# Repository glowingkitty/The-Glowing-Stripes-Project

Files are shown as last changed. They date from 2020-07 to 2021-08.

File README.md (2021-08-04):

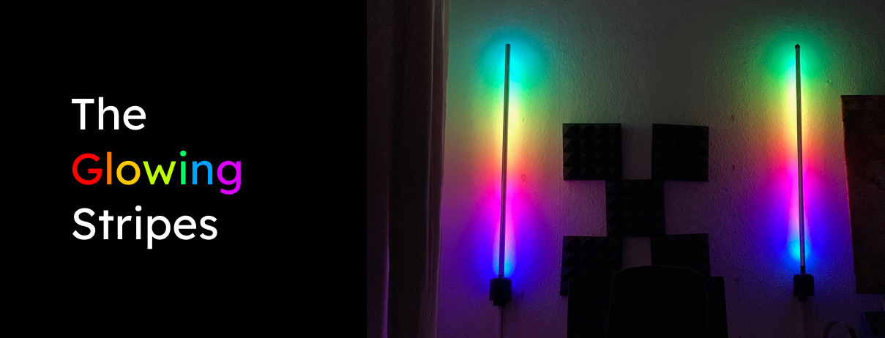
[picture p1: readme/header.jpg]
The Glowing Stripes


## What is this project?

An LED strip system which can be used to light up your home, a house party or even an outdoor party - with it's integrated battery. Every Glowing Stripes unit can glow for many hours in battery mode - or non stop if connected to a power source at home. And with the integrated microphone it's awesome for setting the mood at your home- or openair-party!

How does one control the LED animations, you ask? By accessing the "Glowing Core" interface via your web browser or WLED app for iOS and Android. "The Glowing Core" is a tiny hardware package to control LED strips by the way - and used inside "The Glowing Stripes". [Check out the readme](https://github.com/glowingkitty/TheGlowingCore) to learn more about that project.

## Known issues

Adding a single 1 meter long LED strip (or shorter) to one base unit works perfectly fine. However, when adding multiple LED strips on top of each other, you might notice the LED strips are bending - depending on what kind of material you use for 3D printing the parts. If you 3D print the connecting people out of metal, you shouldn't have to worry. Otherwise it's wise to limit the length to 1 meter per base unit.

## How to build the Glowing Stripes

### **Step 1:** Build the Glowing Core

Check out [the detailed description here](https://github.com/glowingkitty/TheGlowingCore#how-to-build-the-glowing-core) to learn how to build it.

### **Step 2:** 3D print all needed parts

The design was made for printing on an SLA printer (resin 3D printer). But it should also work perfectly fine with an FDM (molten plastic) 3D printer.

Download and print those STL files:

- 1x [main case](https://github.com/glowingkitty/The-Glowing-Stripes-Project/blob/master/3d%20printed%20parts/main_case/main_case.stl)
- 1x [outer case](https://github.com/glowingkitty/The-Glowing-Stripes-Project/blob/master/3d%20printed%20parts/main_case/outer_case.stl)
- 1x [female a connector](https://github.com/glowingkitty/The-Glowing-Stripes-Project/blob/master/3d%20printed%20parts/connector/female_a.stl)
- 1x [female b connector](https://github.com/glowingkitty/The-Glowing-Stripes-Project/blob/master/3d%20printed%20parts/connector/female_b.stl)
- 1x [male a connector](https://github.com/glowingkitty/The-Glowing-Stripes-Project/blob/master/3d%20printed%20parts/connector/male_a.stl) (make sure to use a very strong filament, resin or best: 3d print it with metal)
- 1x [male b connector](https://github.com/glowingkitty/The-Glowing-Stripes-Project/blob/master/3d%20printed%20parts/connector/male_b.stl)

And depending on how you want to position "The Glowing Stripes"...

Stand on furniture or the ground, indoor:

- 1x [mini stand](https://github.com/glowingkitty/The-Glowing-Stripes-Project/blob/master/3d%20printed%20parts/stand/mini_stand.stl)

Hang on the wall:

- 1x [wall stand](https://github.com/glowingkitty/The-Glowing-Stripes-Project/blob/master/3d%20printed%20parts/stand/wall_stand.stl)

Stand outdoor:

- 3x [stand](https://github.com/glowingkitty/The-Glowing-Stripes-Project/blob/master/3d%20printed%20parts/stand/stand.stl)

### **Step 3:** Get all the other parts you need

Here is what you need:

- 1x [22AWG JST Connector 3-Pin Male](https://aliexpress.com/item/1005001779302510.html)
- 1x [22AWG JST Connector 3-Pin Female](https://aliexpress.com/item/1005001779302510.html)
- 1x [V shape aluminium profile - 50cm or 1m](https://aliexpress.com/item/1005002834175693.html)
- 1x [WS2812B LED strip, 30 LEDs per meter, white - 50cm or 1m](https://aliexpress.com/item/2036819167.html)
- (optional) 1x [3000mAh lipo battery](https://www.amazon.de/-/en/Seamuing-Protective-Insulation-Connector-Development/dp/B08V11Z88Q)
- 4x M3 14mm screws
- 4x M3 square nuts

### **Step 4:** Connect The Glowing Core to main case

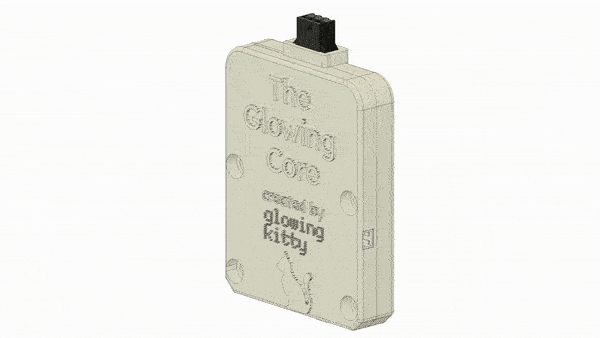
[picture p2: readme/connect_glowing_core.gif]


Add the M3 nuts into the main case, place the Glowing Core in it and screw it together. Optionally: place the 3000mAh lipo inside as well and connect it with The Glowing Core.

### **Step 5:** Finish base unit

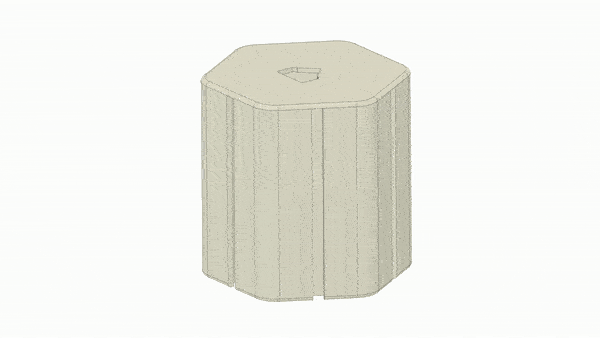
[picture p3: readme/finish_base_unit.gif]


Addd M3 nuts into the outer case, place it on top of the main case and screw it together.

### **Step 6:** Build the connectors

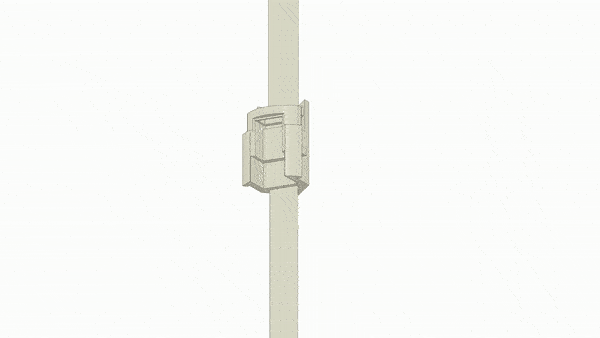
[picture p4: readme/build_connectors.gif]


Place the male 3-pin connector into the male connector a, close it with male connector b and repeat the same for the female connector.

### **Step 7:** Complete the LED strips

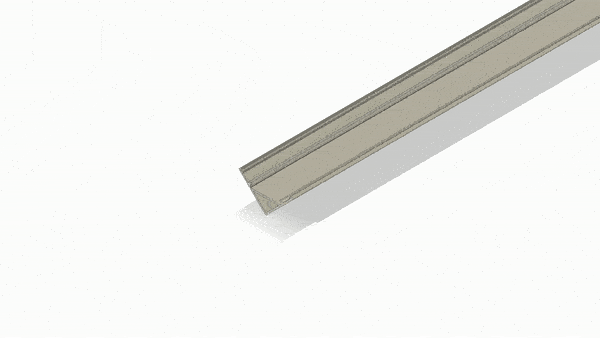
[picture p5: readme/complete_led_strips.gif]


Tape the LED strips on the aluminium profile & remove the foil from the aluminium profile cover, place the connectors on the two ends of the profile and then solder the wires to the LED strips. Make sure the male connector gets soldered to the beginning of the LED strip! Pay attention to the arrow on the WS2812B LED strip (it must point away from the connector). Remove the transparent foil from the aluminium profile diffuser. Then cover the aluminium profile with the diffuser.

### **Step 8:** Complete the Glowing Stripes

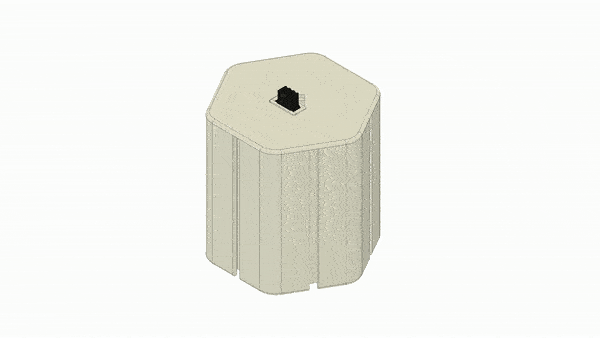
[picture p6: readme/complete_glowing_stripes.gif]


Place the LED strip on the base unit & place the base unit on the stand of your choice.

### **Step 9:** Turn it on and let it glow!

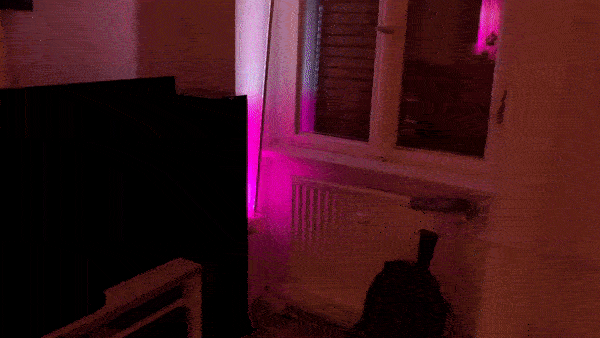
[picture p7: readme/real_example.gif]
Let it glow!


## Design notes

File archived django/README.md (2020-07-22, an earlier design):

# The Glowing Stripes Project

A portable and flexible LED setup. Use it to light up your whole room, or just some area. All stripes are connected via WiFi to the main controller - and can operate for hours without any power plug, thanks to their integrated battery.

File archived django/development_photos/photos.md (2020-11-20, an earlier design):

## The latest development in photos...

The new 3D printed case design (1 of 2 parts - design needs some more smaller fixes):
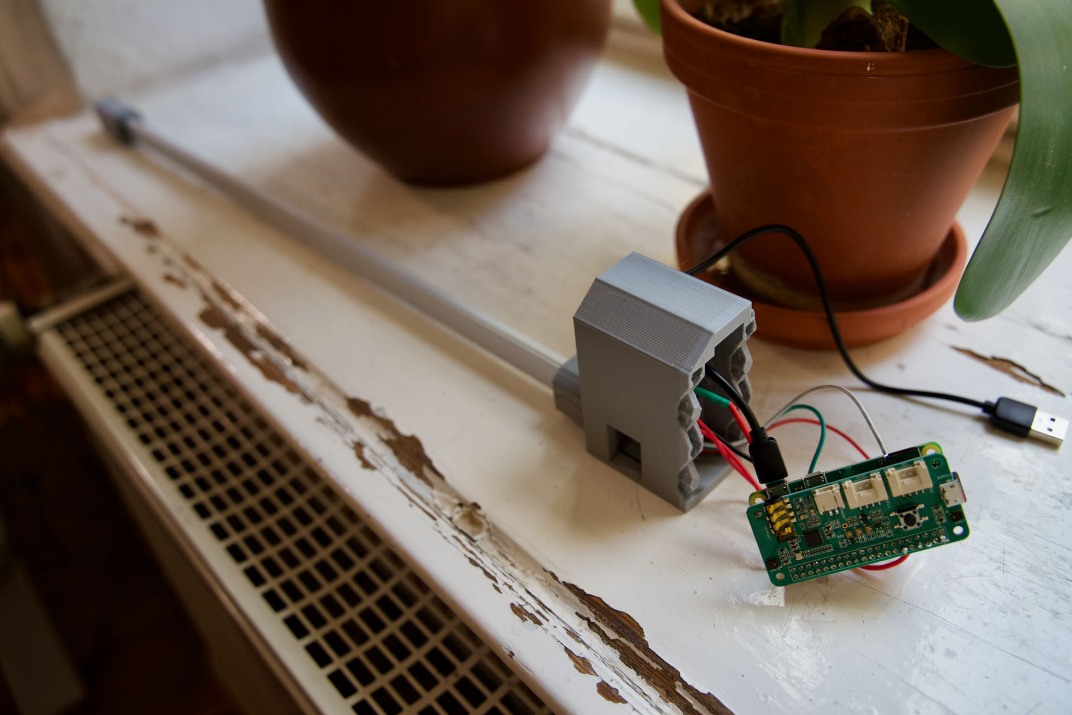
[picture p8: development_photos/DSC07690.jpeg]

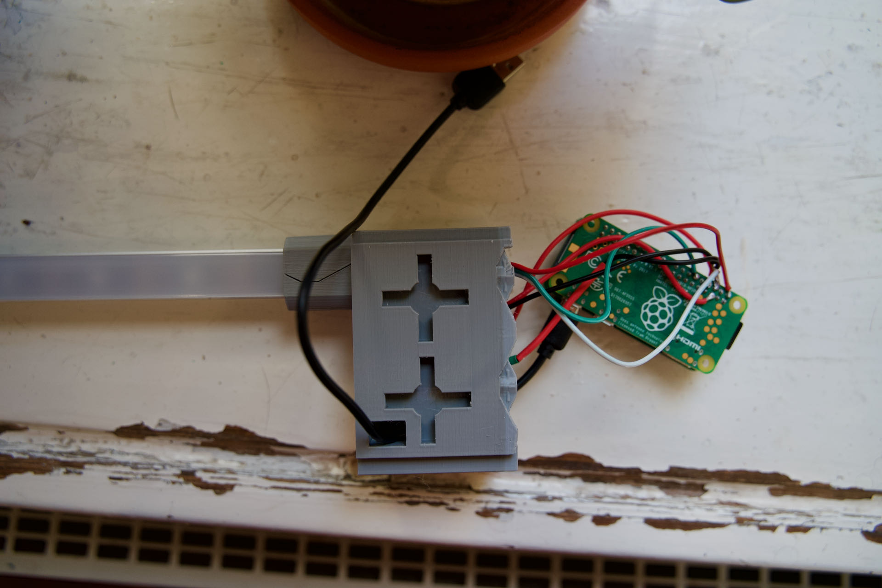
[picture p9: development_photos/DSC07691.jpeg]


Rainbow animation:
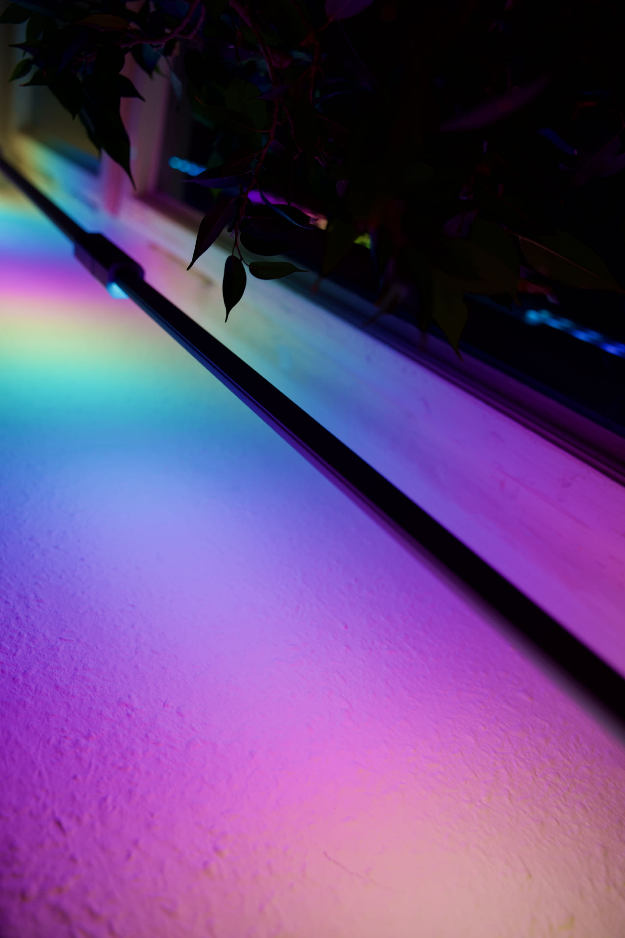
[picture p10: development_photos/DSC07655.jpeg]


The new connector design:
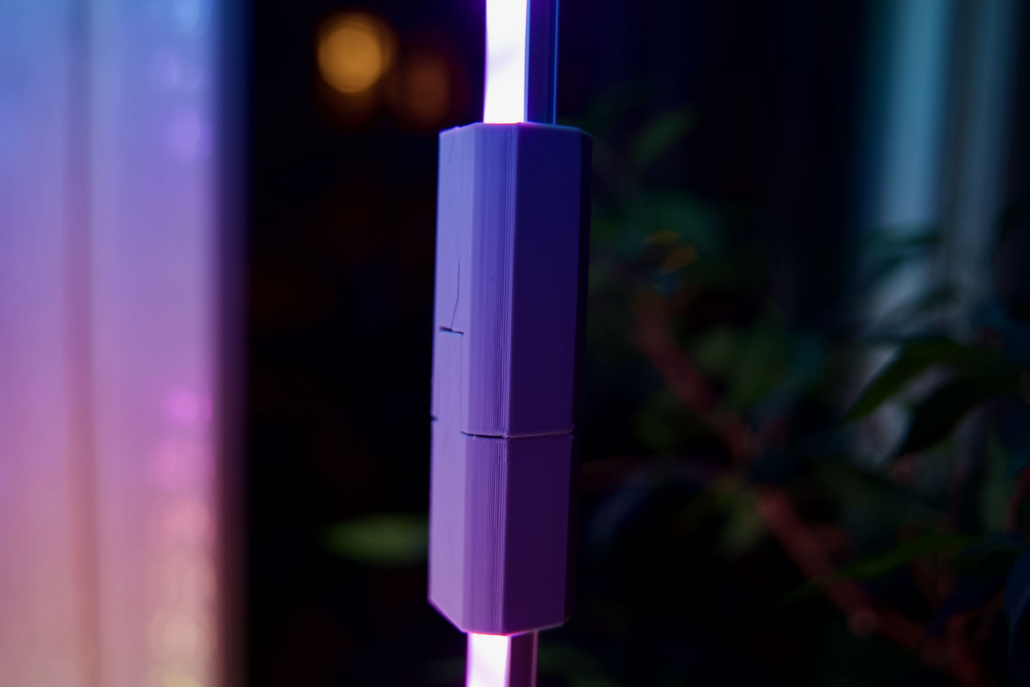
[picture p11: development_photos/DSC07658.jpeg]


New connector + old case design:
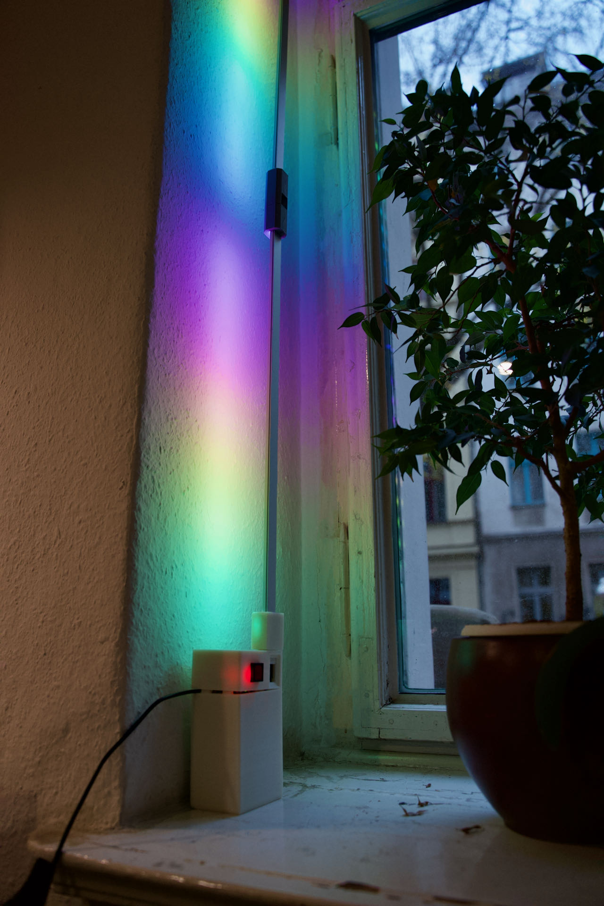
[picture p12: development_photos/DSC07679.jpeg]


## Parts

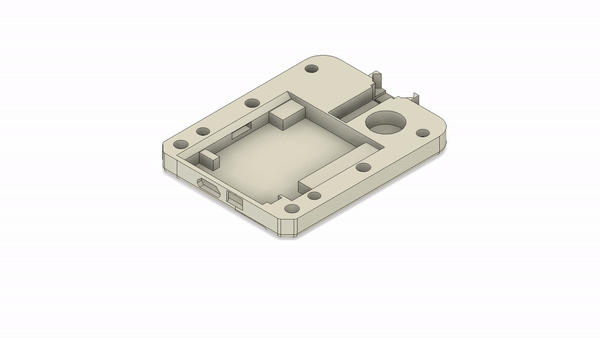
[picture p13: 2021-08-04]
readme/place_components.gif

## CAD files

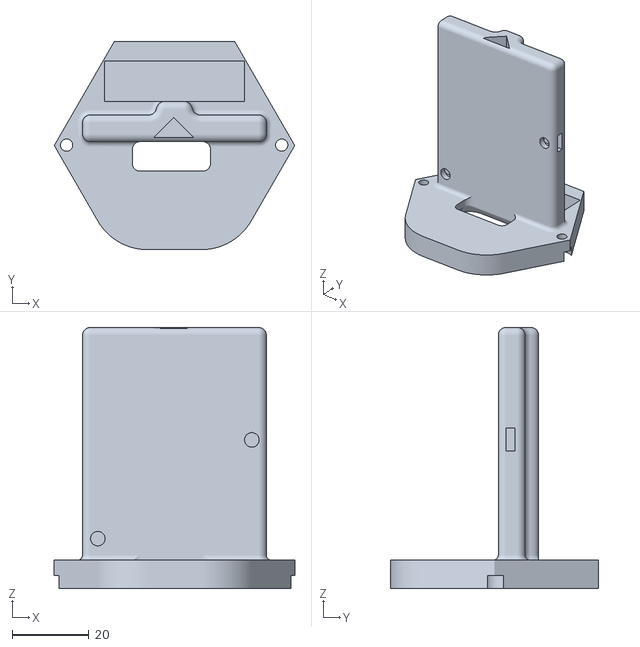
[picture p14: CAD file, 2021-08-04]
3d printed parts/main_case/main_case.stl
62.8 x 54.4 x 68.2

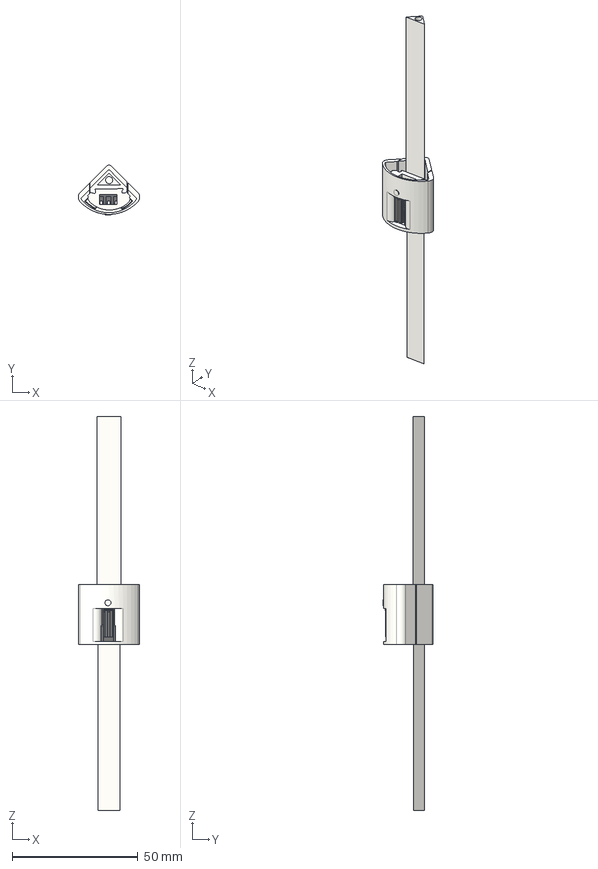
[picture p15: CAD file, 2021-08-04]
3d printed parts/connector/led strip connector male.step
24.4 x 19.8 x 156.4 mm
part a
part b
male

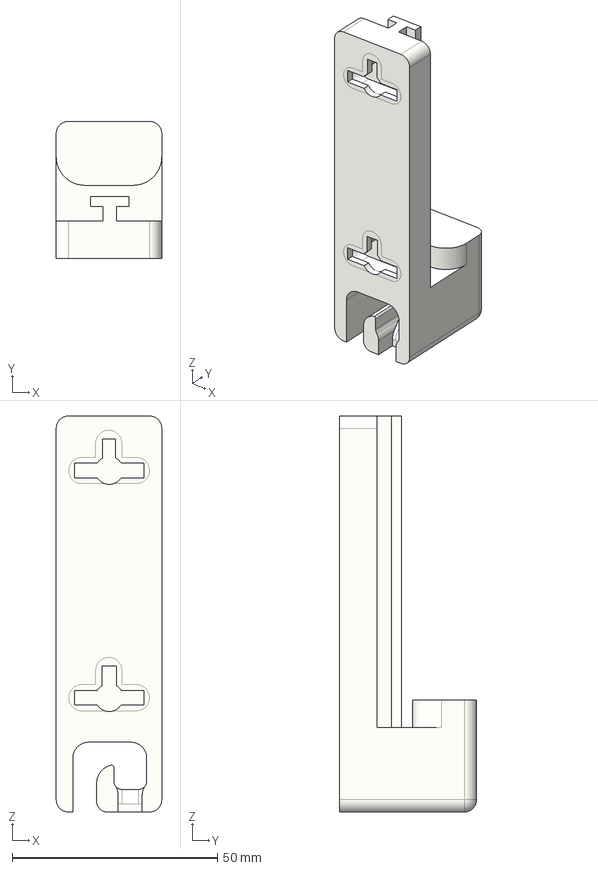
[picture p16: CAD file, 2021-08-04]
3d printed parts/stand/wall stand.step
25.7 x 33.4 x 96.4 mm

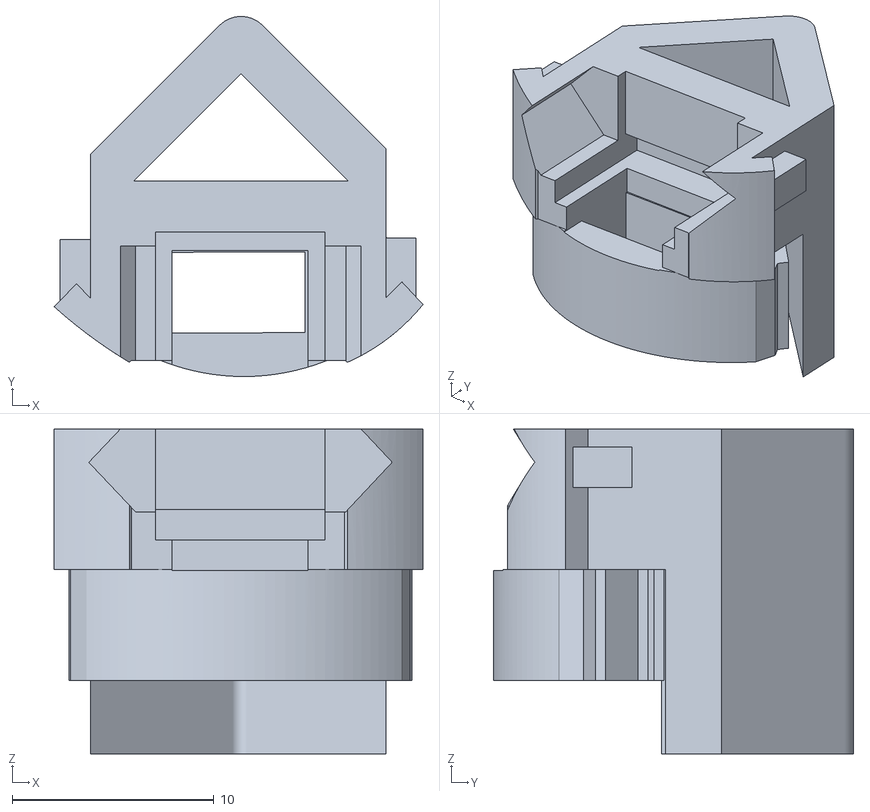
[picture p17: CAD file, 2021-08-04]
3d printed parts/connector/female_a.stl
18.3 x 17.8 x 16.1

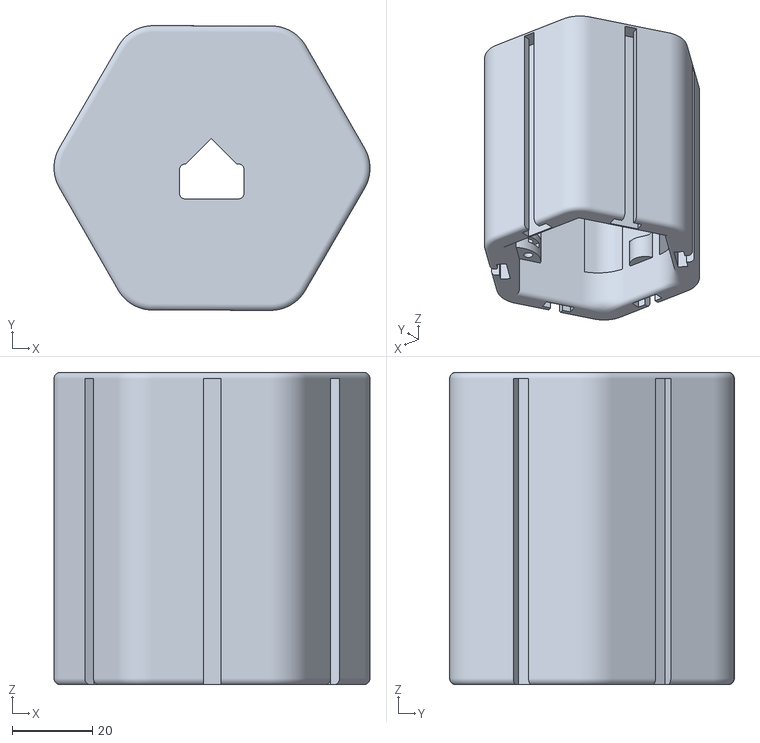
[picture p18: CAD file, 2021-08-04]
3d printed parts/main_case/outer_case.stl
78.9 x 71.1 x 78.0

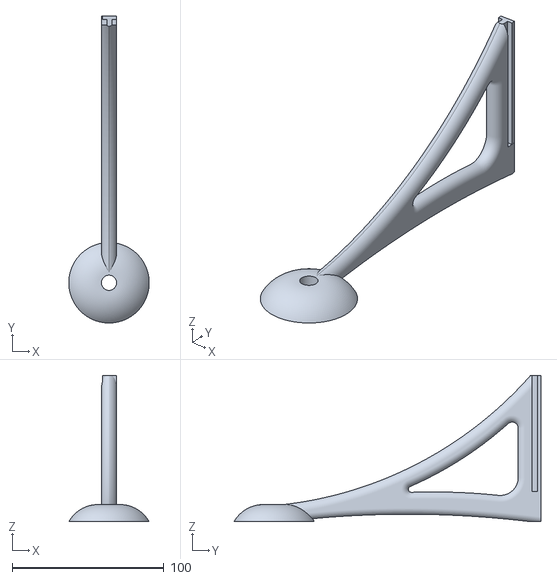
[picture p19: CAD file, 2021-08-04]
3d printed parts/stand/stand.stl
53.0 x 202.3 x 96.4

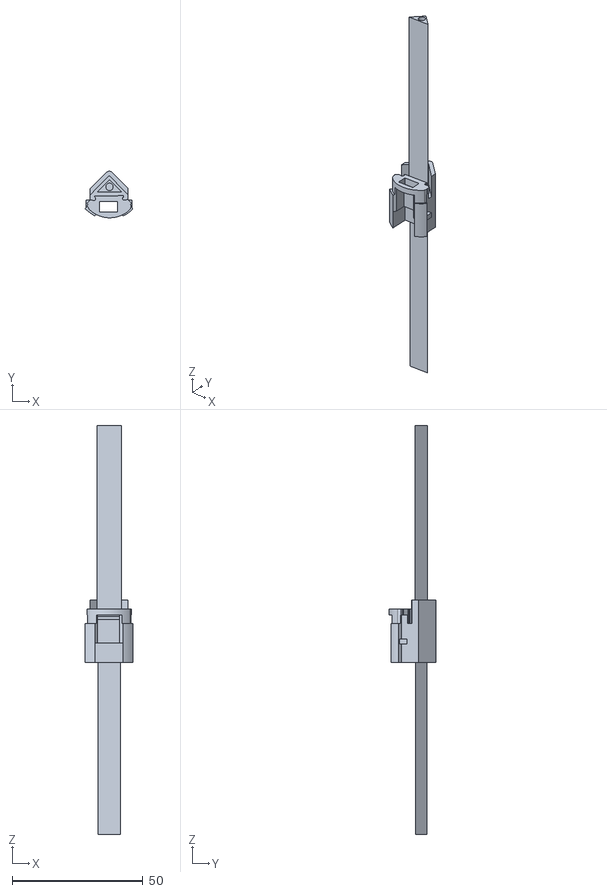
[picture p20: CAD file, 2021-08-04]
3d printed parts/connector/male_a.stl
18.3 x 17.8 x 156.4

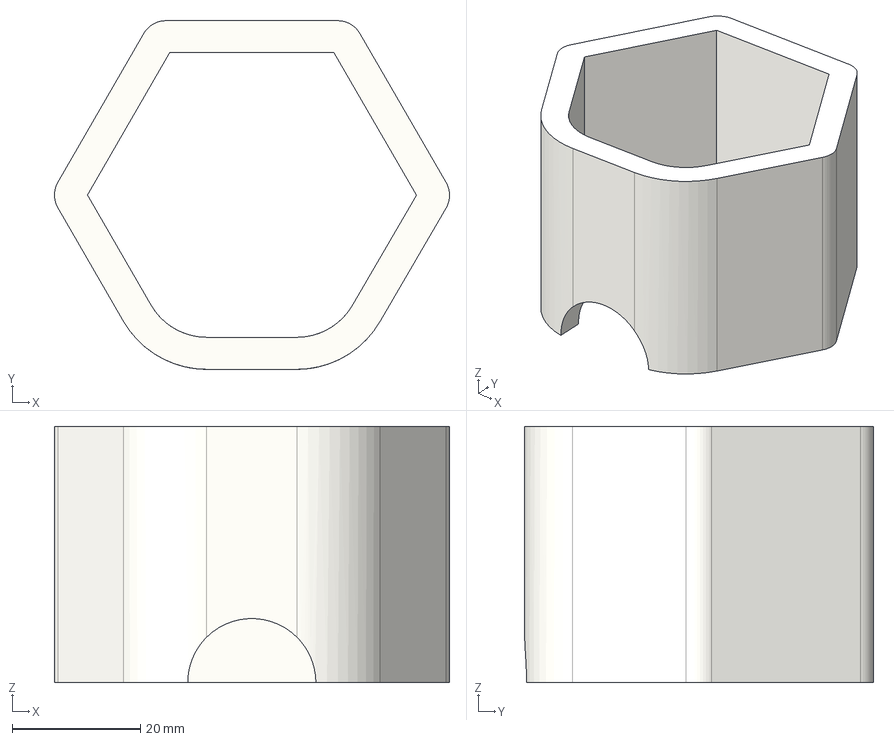
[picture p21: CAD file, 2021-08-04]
3d printed parts/stand/mini stand.step
61.7 x 54.4 x 40.0 mm

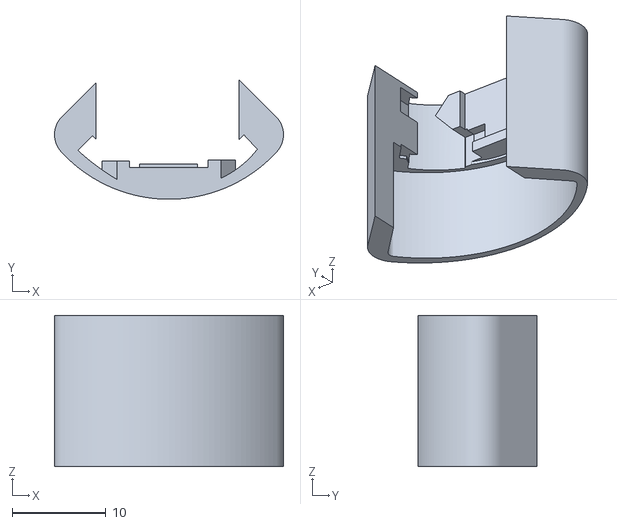
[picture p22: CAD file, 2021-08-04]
3d printed parts/connector/female_b.stl
24.4 x 12.7 x 16.1

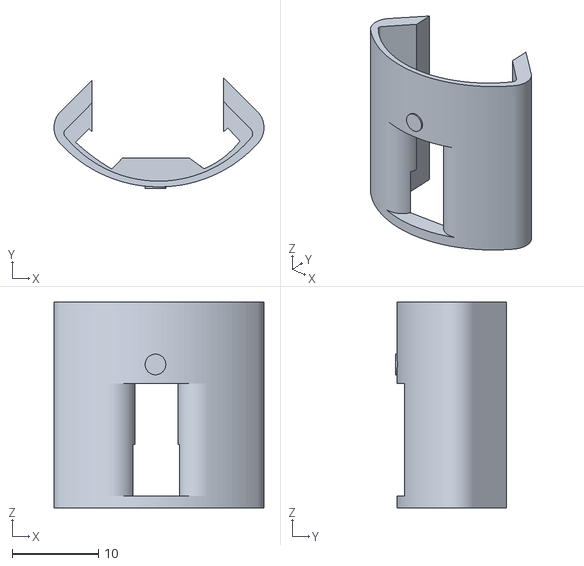
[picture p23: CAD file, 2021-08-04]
3d printed parts/connector/male_b.stl
24.4 x 12.9 x 23.9

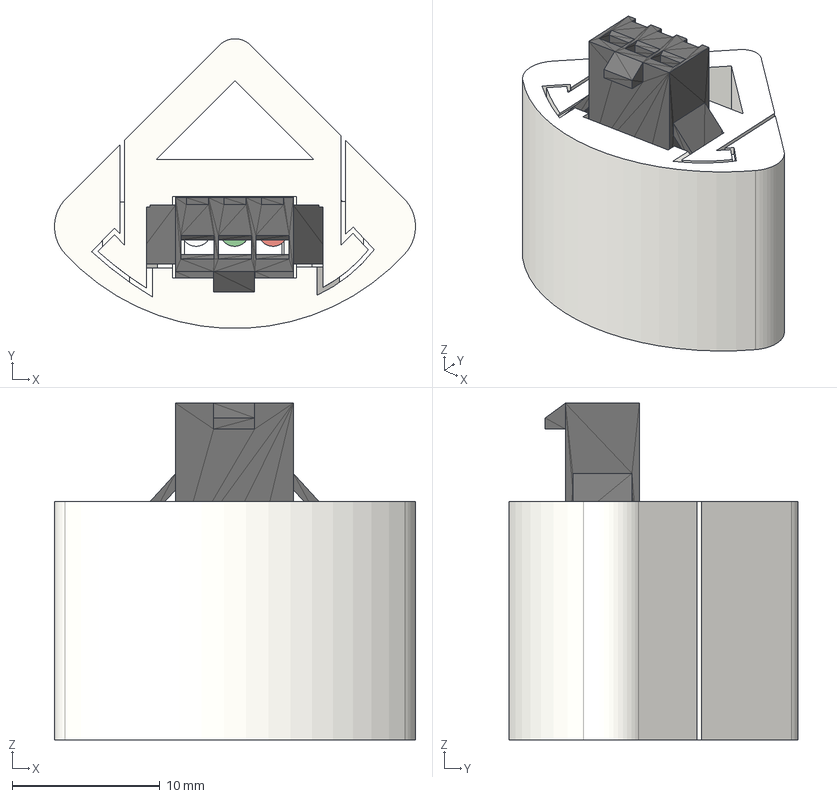
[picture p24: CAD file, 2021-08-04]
3d printed parts/connector/led strip connector female.step
24.4 x 19.6 x 22.8 mm
part a
part b
female (1)

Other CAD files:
3d printed parts/stand/ground stand.step
3d printed parts/connector/led strip connector female.skp
3d printed parts/stand/mini_stand.stl
3d printed parts/stand/wall_stand.stl

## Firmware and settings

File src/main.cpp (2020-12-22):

#include <string>
#include <iostream>
using namespace std;
#include <SPI.h>
#include <SD.h>
#ifdef __AVR__
  #include <avr/power.h>
#endif
#include "wifi_setup.hpp"
#include "neopixel.hpp"
#include "webserver.h"

 #ifdef __cplusplus
  extern "C" {
 #endif

  uint8_t temprature_sens_read();

#ifdef __cplusplus
}
#endif

uint8_t temprature_sens_read();

NeoPixel leds;
WifiSetup wifisetup;

void setup() {
#if defined(__AVR_ATtiny85__) && (F_CPU == 16000000)
    clock_prescale_set(clock_div_1);
#endif
    Serial.begin(115200);               // to enable Serial Commmunication with connected Esp32 board
    
    wifisetup.start_wifi();
    start_server();
}

void loop() {
    Serial.print("ESP32 Temperature: ");
  
    // Give out current temperature in degrees celcius
    Serial.print((temprature_sens_read() - 32) / 1.8);
    Serial.println(" C");
    leds.glow();
}

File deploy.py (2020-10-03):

import argparse
import os


class Deploy():
    def __init__(self):
        parser = argparse.ArgumentParser()
        parser.add_argument("-t", "--target", required=False)
        parser.add_argument("-f", "--firmware", required=False)
        parser.add_argument("-p", "--port", required=False)

        parser.add_argument("-fsh", "--flashfirmware", required=False)
        parser.add_argument("-us", "--uploadserver", required=False)
        args = parser.parse_args()

        self.target_device = args.target if args.target else 'stripe'
        self.firmware_version = args.target if args.target else '1.13'
        self.dev_usb_port = args.target if args.target else '/dev/tty.usbserial-0001'

        self.flash_firmware = args.target if args.target else 'True'
        self.deploy_server = args.target if args.target else 'True'

        self.folders = [
            'files_all_devices',
            'files_host',
            'files_stripe',
            'MicroWebSrv2',
            'www'
        ]

    def install_micropython(self):
        # search for firmware
        firmware = [x for x in os.listdir() if x.startswith(
            'esp32-') and x.endswith(self.firmware_version+'.bin')][0]
        # install esptool
        print('Install esptool...')
        os.system('pip install esptool')
        # format esp
        print('Format ESP...')
        os.system('esptool.py --port {} erase_flash'.format(self.dev_usb_port))
        # copy firmware
        print('Copy firmware...')
        os.system(
            'esptool.py --chip esp32 --port {} --baud 460800 write_flash -z 0x1000 {}'.format(self.dev_usb_port, firmware))

    def install_rshell(self):
        print('Install rshell for copying files to ESP...')
        os.system('pip install rshell')

    def sync_folder(self, folder):
        os.system(
            'rshell --port {} rsync -m {} /pyboard/{}'.format(
                self.dev_usb_port,
                folder,
                folder
            ))

    def copy_file(self, from_path, to_path):
        os.system('rshell --port {} cp {} /pyboard/{}'.format(
            self.dev_usb_port,
            from_path,
            to_path
        ))

    def sync_files(self):
        for folder in self.folders:
            ignore_folder = {"stripe": "host", "host": "stripe"}
            if folder != 'files_'+ignore_folder[self.target_device]:
                print('Sync folder ... ', folder)
                self.sync_folder(folder)

        self.copy_file(
            'files_{}/boot.py'.format(self.target_device), 'boot.py')

    def start(self):
        if self.flash_firmware == 'True':
            self.install_micropython()

        self.install_rshell()
        if self.deploy_server == 'True':
            print('Collecting and uploading files...')
            self.sync_files()
            print('Synced all files to ESP.')
        if self.deploy_server == 'False':
            self.copy_file('files_stripe/neopixel_plus.py', 'neopixel_plus.py')
            self.copy_file('simple_rainbow.py', 'boot.py')
        os.system('screen {} 115200'.format(self.dev_usb_port))


if __name__ == '__main__':
    Deploy().start()

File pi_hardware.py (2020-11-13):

import os
import subprocess

import requests

import iwlist


class PiZeroWH:
    def default_wifi(with_password=True):
        details = {
            'essid': 'TheGlowingStripes',
            'psk': 'letsglow',
            'key_mgmt': 'WPA-PSK'
        } if with_password == True else {
            'essid': 'TheGlowingStripes',
            'current_wifi': False,
            'encryption': 'WPA-PSK',
            'signal_strength': 100
        }
        return details

    def connected_to_internet():
        try:
            if requests.get('https://github.com').status_code == 200:
                return True
            else:
                return False
        except:
            return False

    def current_wifi_network():
        try:
            essid = str(subprocess.run(["iwgetid"], capture_output=True).stdout).split(
                'ESSID:"')[1].split('"')[0]
        except:
            essid = None

        return essid

    def wifi_networks():
        # get wifi networks
        content = iwlist.scan(interface='wlan0')
        networks = iwlist.parse(content)

        # return basics or all details
        current_wifi = PiZeroWH.current_wifi_network()
        networks = [{
            'essid': x['essid'],
            'current_wifi':True if current_wifi == x['essid'] else False,
            'is_default_wifi':True if PiZeroWH.default_wifi()['essid'] == x['essid'] else False,
            'encryption':'WPA-PSK' if x['encryption'] == 'wpa2' else x['encryption'],
            'signal_strength':int(x['signal_quality'])
        } for x in networks]

        # sort them by strength
        networks = sorted(
            networks, key=lambda wifi: wifi['signal_strength'], reverse=True)
        networks = sorted(
            networks, key=lambda wifi: wifi['current_wifi'], reverse=True)

        return networks

    def saved_wifis():
        # open wpa_supplicant.conf
        wpa_supplicant = open(
            "/etc/wpa_supplicant/wpa_supplicant.conf", "r").read()

        # parse networks
        networks_string = 'network='+wpa_supplicant.split('network=', 1)[1]
        networks = [{
            'essid': x.split('ssid="')[1].split('"')[0],
            'psk':x.split('psk="')[1].split('"')[0] if 'psk' in x else None,
            'key_mgmt':x.split('key_mgmt=')[1].split('\n')[0] if 'key_mgmt' in x else None,
        } for x in networks_string.split('network=') if x != '']

        return networks

    def wpa_supplicant_header():
        wpa_supplicant = open(
            "/etc/wpa_supplicant/wpa_supplicant.conf", "r").read()
        header = wpa_supplicant.split('network=', 1)[0]
        return header

    def get_networks_text(networks):
        # make sure to always have PiZeroWH.default_wifi() added as well
        default_wifi = PiZeroWH.default_wifi()
        if default_wifi not in networks:
            networks += [default_wifi]

        networks_text = ''
        for network in networks:
            networks_text += '\n'
            networks_text += 'network={\n'
            networks_text += '        ssid="{}"\n'.format(
                network['essid'])
            networks_text += '        psk="{}"\n'.format(network['psk'])
            networks_text += '        key_mgmt={}\n'.format(
                network['key_mgmt'])
            networks_text += '}\n'
        return networks_text

    def add_wifi(essid, password, encryption='WPA-PSK', position='start'):
        # add wifi to wpa_supplicant.conf, if it doesn't exist yet
        networks = PiZeroWH.saved_wifis()

        # check if wifi already in list
        new_wifi = {'essid': essid, 'psk': password, 'key_mgmt': encryption}
        if new_wifi in networks:
            if position == 'start' and new_wifi == networks[0]:
                print(
                    '"{}" already saved as No. 1 wifi in wpa_supplicant.conf'.format(essid))
            elif position != 'start' and new_wifi != networks[0]:
                print('"{}" already saved in wpa_supplicant.conf'.format(essid))
            else:
                print('Update order of wifi networks...')
                if position == 'start':
                    networks = [new_wifi] + \
                        [x for x in networks if x != new_wifi]
                else:
                    networks = [x for x in networks if x !=
                                new_wifi]+[new_wifi]

                wpa_supplicant = PiZeroWH.wpa_supplicant_header()+PiZeroWH.get_networks_text(networks)
                f = open("/etc/wpa_supplicant/wpa_supplicant.conf", "w")
                f.write(wpa_supplicant)
                f.close()
                print('Updated order of wifi networks')

        else:
            print('Adding {} to wpa_supplicant.conf...'.format(essid))
            if position == 'start':
                networks.insert(0, new_wifi)
            else:
                networks += [new_wifi]

            # build new wpa_supplicant.conf
            wpa_supplicant = PiZeroWH.wpa_supplicant_header()+PiZeroWH.get_networks_text(networks)
            f = open("/etc/wpa_supplicant/wpa_supplicant.conf", "w")
            f.write(wpa_supplicant)
            f.close()
            print('Added {} to wpa_supplicant.conf'.format(essid))

    def remove_wifi(essid):
        default_wifi = PiZeroWH.default_wifi()
        if essid == default_wifi['essid']:
            print('Cannot remove {}, its the default wifi network TheGlowingStripesProject will create in case there is no other wifi accessible'.format(
                default_wifi['essid']))
        else:
            print('Remove {} from wpa_supplicant.conf...'.format(essid))
            networks = [x for x in PiZeroWH.saved_wifis()
                        if x['essid'] != essid]
            wpa_supplicant = PiZeroWH.wpa_supplicant_header()+PiZeroWH.get_networks_text(networks)
            f = open("/etc/wpa_supplicant/wpa_supplicant.conf", "w")
            f.write(wpa_supplicant)
            f.close()
            print('Updated wpa_supplicant.conf')

    def restart_wifi():
        # restart wifi related services
        print('Restarting wifi (autohotspot.service)...')
        os.system('sudo systemctl restart autohotspot')
        print('Wifi restarted')

    def connect_to_wifi(essid, password, encryption):
        # add wifi if it doesn't exist yet
        PiZeroWH.add_wifi(essid, password, encryption)
        PiZeroWH.restart_wifi()

    def disconnect_from_wifi(essid):
        # disconnect from wifi by moving "TheGlowingStripes" default network to top and restart wifi (authotspot.service)
        default_wifi = PiZeroWH.default_wifi()
        PiZeroWH.remove_wifi(essid)
        PiZeroWH.add_wifi(
            default_wifi['essid'], default_wifi['psk'], default_wifi['key_mgmt'])
        PiZeroWH.restart_wifi()

    def off():
        # shutdown raspberry pi
        os.system("shutdown now -h")

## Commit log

2020-08-07 update 3D model
    [glowing_stripes.blend]
2020-09-13 redirect input signal to led strip (in dev)
2020-09-13 try fix led strip (in dev)
2020-09-13 try fix led code (in dev)
2020-09-14 added lasercutting files for case (v1 for testing)
    [glowing_stripes.blend]
2020-09-15 enable wireless sync of LED mode (based on NeoPixelPlus LED modes)
2020-09-21 simplify and fix "get_current_mode"
    [stripe.py]
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2020-09-22 fix update issues by making update quicker
    [stripe.py]
2020-09-22 remove fixed led strip IP and started to add function to save errors (in progress)
    [host.py, stripe.py]
2020-09-25 auto add LED strips based on json on boot
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2020-09-27 updated base case, stripes and added controller case
2020-09-27 fixed checkbox buttons
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2020-09-28 added new case, renamed old case and continued with frontend
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2020-09-30 fixed showing current led animation and settings & remove need for internet connection
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2020-10-01 separate files more, start fixing memory error by downgrading firmware and create easy setup script
    [host.py, stripe.py]
2020-10-22 switched to django as a web server (in dev)
2020-10-25 auto start last used led animation + added 3d print models (in progress)
    [case_back.stl, case_front.stl, case_slider.stl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]
2020-10-27 updated connector 3d model, made stripe signup in interface work
    [connector.stl]
2020-10-27 fixed switching to setup mode
    [stripe.py]
2020-10-29 added shutdown via web interface & physical button + started adding led animation preview in browser (in dev)
2020-10-29 updated 3d models for case and connector
    [case_back.stl, case_bottom.stl, case_front.stl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]
2020-11-05 updated 3d models for connector and case + updated diagram
    [battery_extender.stl, battery_extender_cap.stl, case_bottom.stl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]
2020-11-06 updated 3d models for easier printing & prevent stripe ID conflicts
    [battery_extender.stl, battery_extender_cap_part_b.stl, battery_extender_part_a.stl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]
2020-11-08 replaced boot.py with connect_to_host & start_animation + removed ESP related old files + added buttons
    [connect_to_host.py, stripe.py]
2020-11-09 added software update popup, power options & made it easier to setup systemd services
2020-11-09 fixed restart server last
    [services.py]
2020-11-10 added wifi reset button and icons to 3d print + added wifi icons
    [main_case.stl, main_case_part_a.stl]
2020-11-11 added more space to easier remove battery extender
    [battery_extender.stl, battery_extender_cap_part_b.stl]
2020-11-11 added stand for improved stability when standing indoor without battery extension
    [stand.stl]
2020-11-11 split up classes for power, software_update + started working on wifi.js
2020-11-12 created new connector, since previous one wasnt stable enough
    [connector.stl, four_connectors.stl, part_a_1.stl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]
2020-11-12 decreased width of aluminium profile cutout, for better fit
    [connector.stl, four_connectors.stl, part_a_1.stl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]
2020-11-12 reduce requests to server to minimize cpu usage and prevent performance problems
    [connect_to_host.py]
2020-11-14 updated connector design (round + better aluminium profile cutout)
    [connector.stl, four_connectors.stl, part_a_1.stl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]
2020-11-14 update services.py and fix autohotspot service
    [connect_to_host.py, services.py]
2020-11-14 connect/disconnect wifi for all led strips, not just host
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2020-11-16 fixed mode change not saved and added off mode
    [stripe.py]
2020-11-17 last small fixes to connector for better fit of part a
    [connector.stl, four_connectors.stl, part_a_1.stl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]
2020-11-17 replaced battery extender with easier to remove sliding mechanism
    [battery_extender.stl, battery_extender_cap_part_b.stl, battery_extender_part_a.stl]
2020-11-18 added new stand, updated battery extender and removed outdated main case (new in dev)
    [battery_extender.stl, battery_extender_cap.stl, battery_extender_cap_part_a.stl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]
2020-11-18 updated battery extender and main case
    [battery_extender_cap.stl, battery_extender_cap_part_a.stl, main_case.stl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]
2020-11-19 move "edit layout" button to bottom for cleaner layout
2020-11-20 small fixes to connector for better stability
    [connector.stl, four_connectors.stl, part_a_1.stl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]
2020-11-20 removed main case cap to connector for better stability - and rounded edges
    [battery_extender_cap.stl, battery_extender_cap_part_a.stl, battery_extender_cap_part_b.stl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]
2020-11-21 added default customizations to led_animations.json and worked on adding functions for "colors" field
2020-11-25 added change_num_of_random_colors and made it easier to track if animation has changed
2020-12-04 hide "apply","update","save" button by default and show on change
2020-12-04 recognice changes in led animation customizer correctly
2020-12-04 make apply changes button work and show real generated random colors in frontend as well
2020-12-04 fix executing animation error
    [stripe.py]
2020-12-04 fix submitting current_animation_rgb_colors
2020-12-04 prevent crash because of setup animation
    [stripe.py]
2020-12-06 show random generated colors when switching led mode. Next: also show correct colors when loading interface
    [stripe.py]
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2020-12-08 fix selecting sections in led customizer
2020-12-08 fix undo changes button
2020-12-10 enable customize led mode without having to apply it first
2020-12-13 show "save" and "reset" button if there are unsaved changes for an animation
2020-12-13 don't hide save button if still unsaved changes
2020-12-15 enable "reset changes" button
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2020-12-23 split up esp code into 2 separate esp modules (because of led strip flickering)
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2020-12-26 auto connect led strip with webserver and get led strip info (in progress)
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2020-12-27 get correct led stripe information based on local json file
    [main.cpp]
2020-12-29 redesigned case, connector and stand for v shaped aluminium profile
    [battery_extender_cap.stl, battery_extender_cap_part_a.stl, battery_extender_cap_part_b.stl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]
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2021-01-19 reduce code to one esp32 only for both webserver and led animation
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2021-02-01 considered sections for led strips + started adding other animations (in dev)
2021-02-01 fix reloading config file between animations
    [main.cpp]
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2021-02-08 added custom data pin, simplified code and added core info to comments for better debugging
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2021-02-20 use two esp32 (one for webserver, one for animations) to fix flickering LEDs issue
    [main.cpp]
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2021-02-22 OTA on led strip by default off, to prevent flickering, can be activated via /activate_ota
    [main.cpp]
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2021-03-02 added more fields to stripe_config, enabled showing connected led strips on start page
2021-03-03 fix updating mode via serial
    [main.cpp]
2021-03-30 updated 3d printed case, connectors, esp32 cases, script to update software
    [PLA_PETG_esp32_d1_top_case_mold_top_layer.stl, PLA_PETG_mold_case.stl, PLA_mold_for_silicon_mold_1_esp32_d1_top.stl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]
2021-04-20 updated 3d printed cases and connectors and diagram
    [back_cover.3mf, back_cover.stl, bottom_cover.3mf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]
2021-04-24 bug fixes related to signing up led strips
2021-04-29 make start & end setup mode work, changed connector 3d prints
    [female.3mf, female_a.stl, female_b.stl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]
2021-05-06 auto check config on boot, updated connector & case design & more
    [case.stl, cover.stl, female.3mf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]
2021-05-10 Fixed crashes, improved 3d prints
    Fixed:
    - Crash when starting setup mode (function taking the AdafruitNeopixel
    class as input was the issue)
    Improvements:
    - esp32_d1_case_bottom.stl: more space for wires leaving the case
    (needed for adding wires for debugging hardware)
    - main_case.stl: further improvements (honestly forgot what kind...)
    [esp32_d1_case_bottom.stl, main_case.stl]
2021-05-11 Completed setup_mode & more fixes
    Done:
    - setup_mode: starting and ending setup_mode works now
    In progress:
    - control interface: working on fixing interface to control LED strips
    & change animations
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2021-05-23 updated code, cleaned repo, updated prints
    What changed:
    - continued adding software update via internet
    - added new GlowingCore case & more changes to other 3d prints
    - changed theglowingstripes.local to glow.local for better usability
    - removed photos which are not relevant at the moment
    [case_a.stl, case_b.stl, case_c.stl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]
2021-05-27 improved performance & 3d prints, notifications
    - SVG files are now embedded inline for better performance
    - update case 3d model
    - added notification for software updates
    - added popup for software updates
    - next: start software update via frontend and see progress
    [case_a.stl, case_d.stl, full_case.3mf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]
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2021-06-08 clean up & updated case and wall stand
    [case_a.stl, case_b.stl, case_c.stl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]
2021-08-04 using Glowing Core now as foundation, added readme
    [PLA_PETG_esp32_d1_top_case_mold_top_layer.stl, PLA_PETG_mold_case.stl, PLA_mold_for_silicon_mold_1_esp32_d1_top.stl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]
